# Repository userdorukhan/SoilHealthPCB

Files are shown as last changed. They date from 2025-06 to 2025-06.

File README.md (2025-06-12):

# 🌱 SoilHealth – Smart Agriculture PCB Project

**SoilHealth** is a smart environmental monitoring system designed as part of the Hope DeCal at UC Berkeley. This project aims to measure key soil and atmospheric parameters to support precision agriculture, gardening, and sustainability efforts. The custom-designed PCB integrates multiple sensors, solar-powered charging, and wireless data transmission via an ESP32 microcontroller.

---

## 🔧 Features

* **Custom PCB Design** for low-power, compact, and modular sensor integration
* **Solar-Powered System** with a Li-ion battery and charging circuit
* **ESP32 Microcontroller** for sensor interfacing and Wi-Fi communication
* **U.FL Antenna Connector** for extended wireless range
* **Data Logging** to Firebase for real-time remote monitoring

---

## 🌡️ Sensors Used

| Sensor  | Measurement | Notes |
| --- | --- | --- |
| SEN0193 | Soil Moisture | Capacitive, analog output |
| DS18B20 | Soil Temperature | Waterproof, 1-Wire protocol |
| BH1750  | Light Intensity | Digital I2C sensor |
| BME280  | Temperature, Humidity, Pressure | I2C protocol |

---

## ⚡ Power Management

* **Solar Panel Input**
* **Lithium-Ion Battery** charging via onboard circuit
* **Voltage Regulator** to ensure stable 3.3V supply to ESP32 and sensors

---

## 📡 Connectivity

* **Wi-Fi Transmission** via ESP32
* **Firebase Integration** for remote data storage and visualization

---

## 📐 PCB Highlights

* Designed using KiCad
* Double-layer board optimized for low noise and compact routing
* Separate power domain for analog sensors to reduce interference
* Test points for debugging and voltage verification

---

## 🛠️ Future Improvements

* Add onboard SD card logging for offline operation
* Improve power optimization via deep sleep modes
* Add additional sensors (e.g., CO₂, VOC) for advanced monitoring

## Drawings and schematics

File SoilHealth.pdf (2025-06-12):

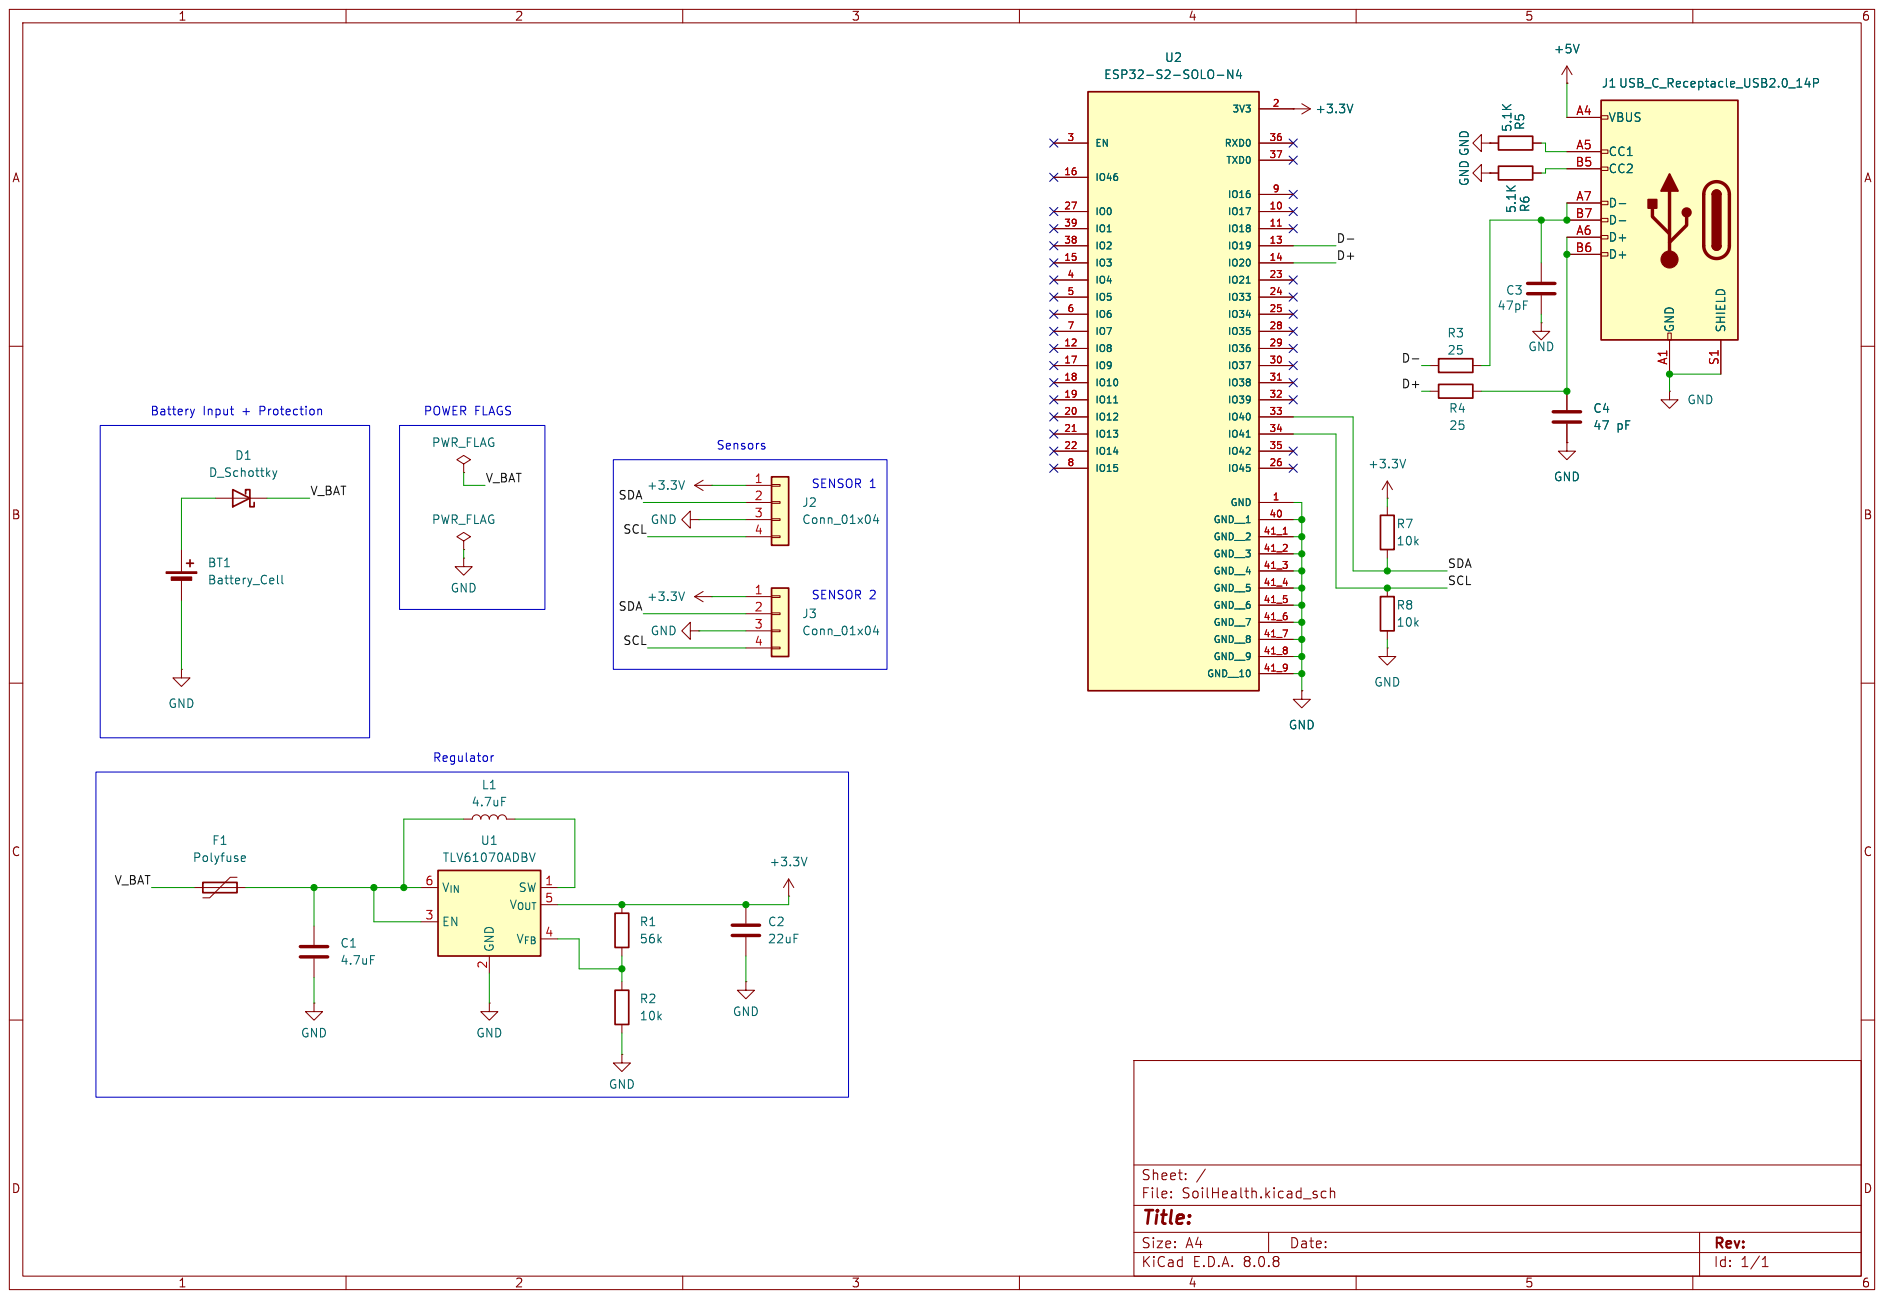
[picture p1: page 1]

Id: 1/1 Title: File: SoilHealth.kicad_sch Sheet: / GND

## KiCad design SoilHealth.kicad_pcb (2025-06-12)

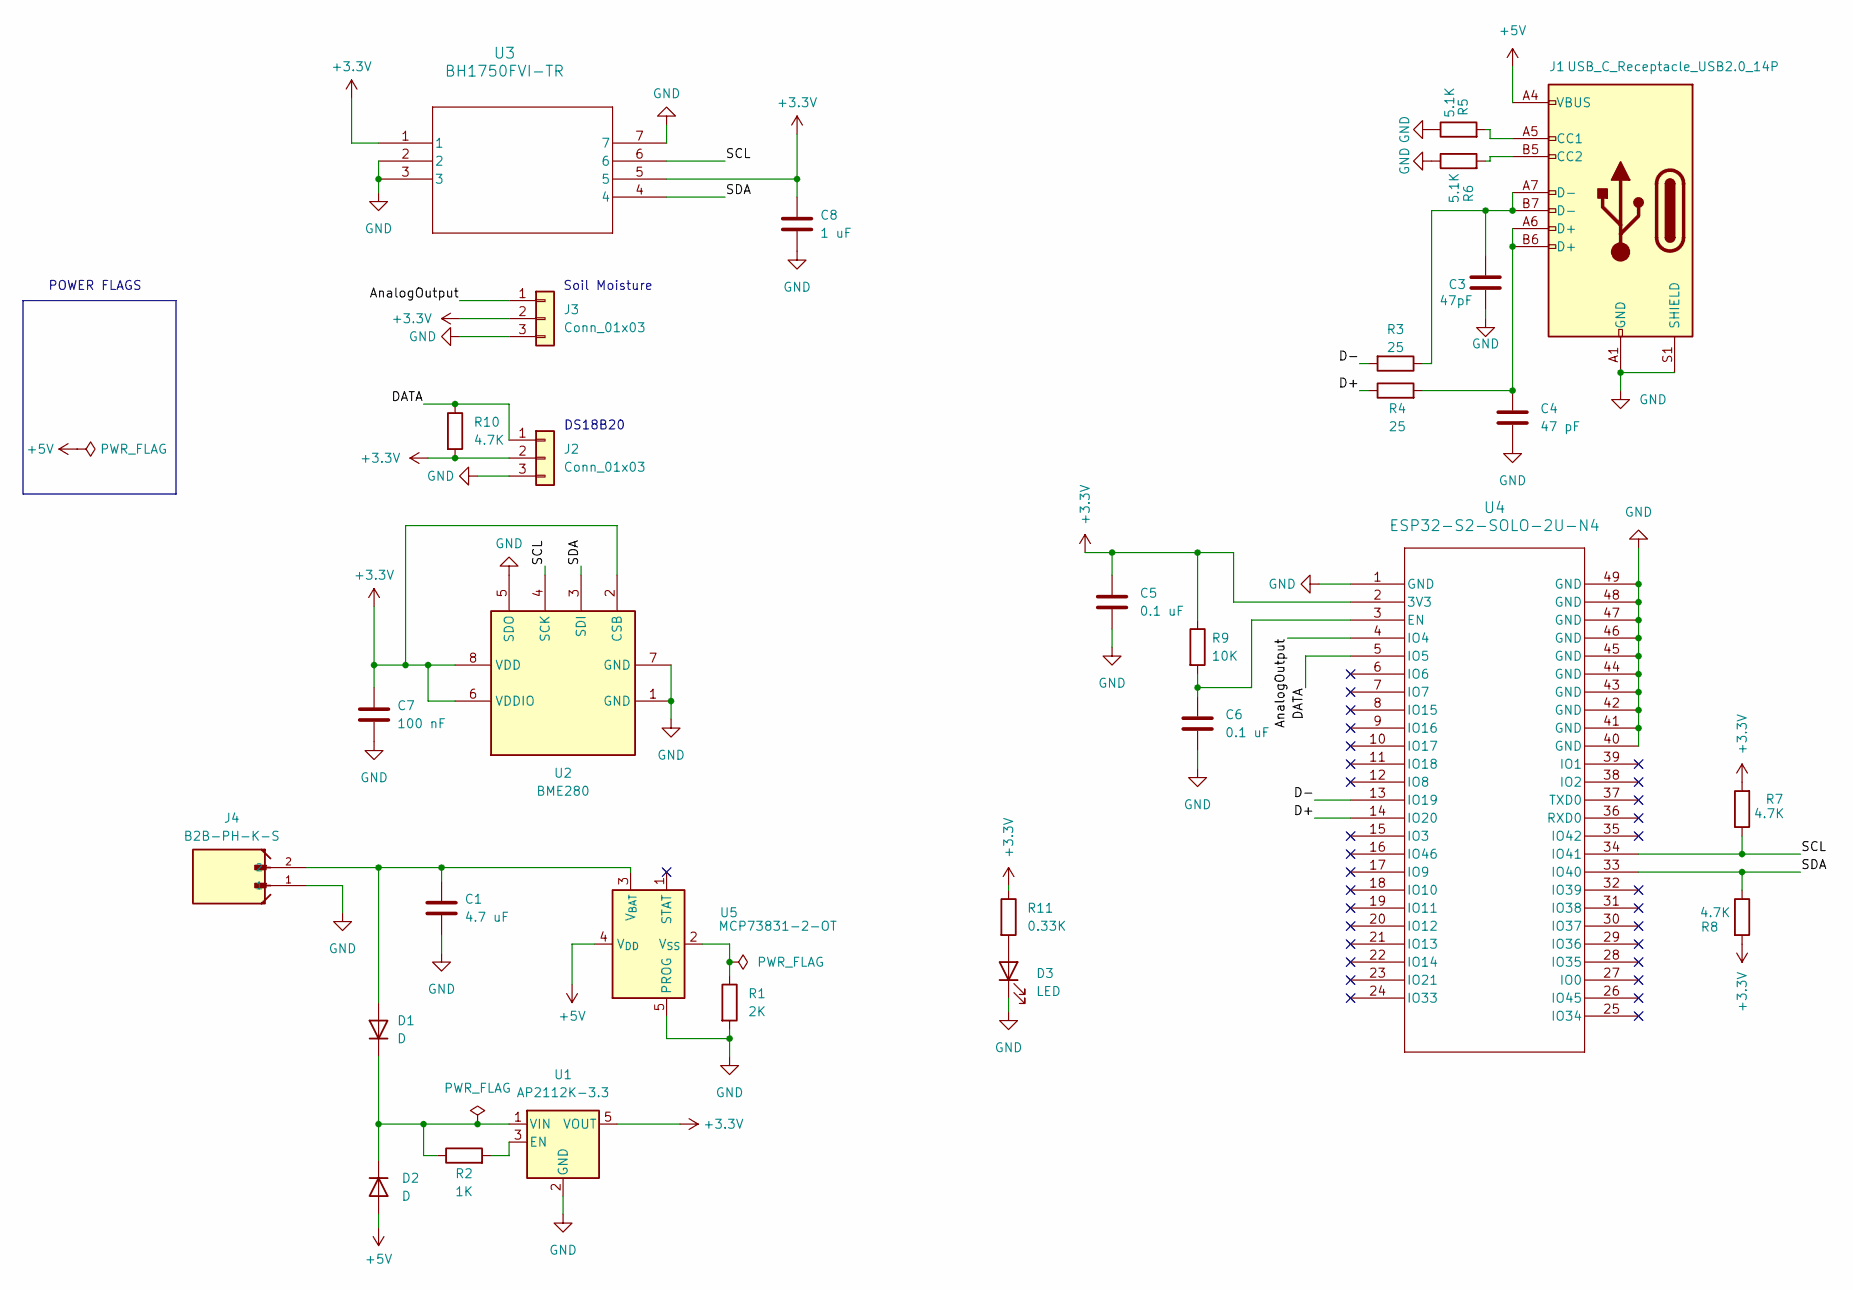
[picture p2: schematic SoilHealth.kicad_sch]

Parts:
C1: 4.7 uF; C_0603_1608Metric_Pad1.08x0.95mm_HandSolder
C3: 47pF; C_0603_1608Metric_Pad1.08x0.95mm_HandSolder
C4: 47 pF; C_0603_1608Metric_Pad1.08x0.95mm_HandSolder
C5, C6: 0.1 uF; C_0603_1608Metric_Pad1.08x0.95mm_HandSolder
C7: 100 nF; C_0603_1608Metric_Pad1.08x0.95mm_HandSolder
C8: 1 uF; C_0603_1608Metric_Pad1.08x0.95mm_HandSolder
D1, D2: D; D_SMA
D3: LED; D_0603_1608Metric_Pad1.05x0.95mm_HandSolder
J1: USB_C_Receptacle_USB2.0_14P; USB_C_Receptacle_GCT_USB4105-xx-A_16P_TopMnt_Horizontal
J2: Conn_01x03; PinSocket_1x03_P2.54mm_Vertical
J3: Conn_01x03; PinHeader_1x03_P2.54mm_Vertical
J4: B2B-PH-K-S; BatteryHead
R1: 2K; R_0603_1608Metric_Pad0.98x0.95mm_HandSolder
R2: 1K; R_0603_1608Metric_Pad0.98x0.95mm_HandSolder
R3, R4: 25; R_0603_1608Metric_Pad0.98x0.95mm_HandSolder
R5, R6: 5.1K; R_0603_1608Metric_Pad0.98x0.95mm_HandSolder
R7, R8, R10: 4.7K; R_0603_1608Metric_Pad0.98x0.95mm_HandSolder
R9: 10K; R_0603_1608Metric_Pad0.98x0.95mm_HandSolder
R11: 0.33K; R_0603_1608Metric_Pad0.98x0.95mm_HandSolder
U1: AP2112K-3.3; SOT-23-5
U2: BME280; Bosch_LGA-8_2.5x2.5mm_P0.65mm_ClockwisePinNumbering
U3: BH1750FVI-TR; LightEmmity
U4: ESP32-S2-SOLO-2U-N4; ESP32-S2-SOLO-2U_EXP
U5: MCP73831-2-OT; SOT-23-5

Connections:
+3.3V: C5.1, C7.1, C8.1, J2.2, J3.2, R7.2, R8.2, R9.1, R10.2, R11.1, U1.5 (VOUT), U2.2 (CSB), U2.6 (VDDIO), U2.8 (VDD), U3.1, U3.5, U4.2 (3V3)
+5V: D2.2 (A), J1.A4 (VBUS), J1.A9 (VBUS), J1.B4 (VBUS), J1.B9 (VBUS), U5.4 (V_{DD})
/AnalogOutput: J3.1, U4.4 (IO4)
/D+: R4.1, U4.14 (IO20)
/D-: R3.2, U4.13 (IO19)
/DATA: J2.1, R10.1, U4.5 (IO5)
/SCL: R7.1, U2.4 (SCK), U3.6, U4.34 (IO41)
/SDA: R8.1, U2.3 (SDI), U3.4, U4.33 (IO40)
GND: C1.2, C3.2, C4.2, C5.2, C6.2, C7.2, C8.2, D3.1 (K), J1.A1 (GND), J1.A12 (GND), J1.B1 (GND), J1.B12 (GND), J1.S1 (SHIELD), J2.3, J3.3, J4.1, R1.2, R5.1, R6.1, U1.2 (GND), U2.1 (GND), U2.5 (SDO), U2.7 (GND), U3.2, U3.3, U3.7, U4.1 (GND), U4.40 (GND), U4.41 (GND), U4.42 (GND), U4.43 (GND), U4.44 (GND), U4.45 (GND), U4.46 (GND), U4.47 (GND), U4.48 (GND), U4.49 (GND), U5.5 (PROG)
unnamed: C3.1, J1.A7 (D-), J1.B7 (D-), R3.1
unnamed: C4.1, J1.A6 (D+), J1.B6 (D+), R4.2
unnamed: C1.1, D1.2 (A), J4.2, U5.3 (V_{BAT})
unnamed: D1.1 (K), D2.1 (K), R2.1, U1.1 (VIN)
unnamed: D3.2 (A), R11.2
unnamed: J1.A5 (CC1), R5.2
unnamed: J1.B5 (CC2), R6.2
unnamed: R2.2, U1.3 (EN)
unnamed: C6.1, R9.2, U4.3 (EN)
unnamed: R1.1, U5.2 (V_{SS})

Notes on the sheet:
POWER FLAGS
Soil Moisture
DS18B20

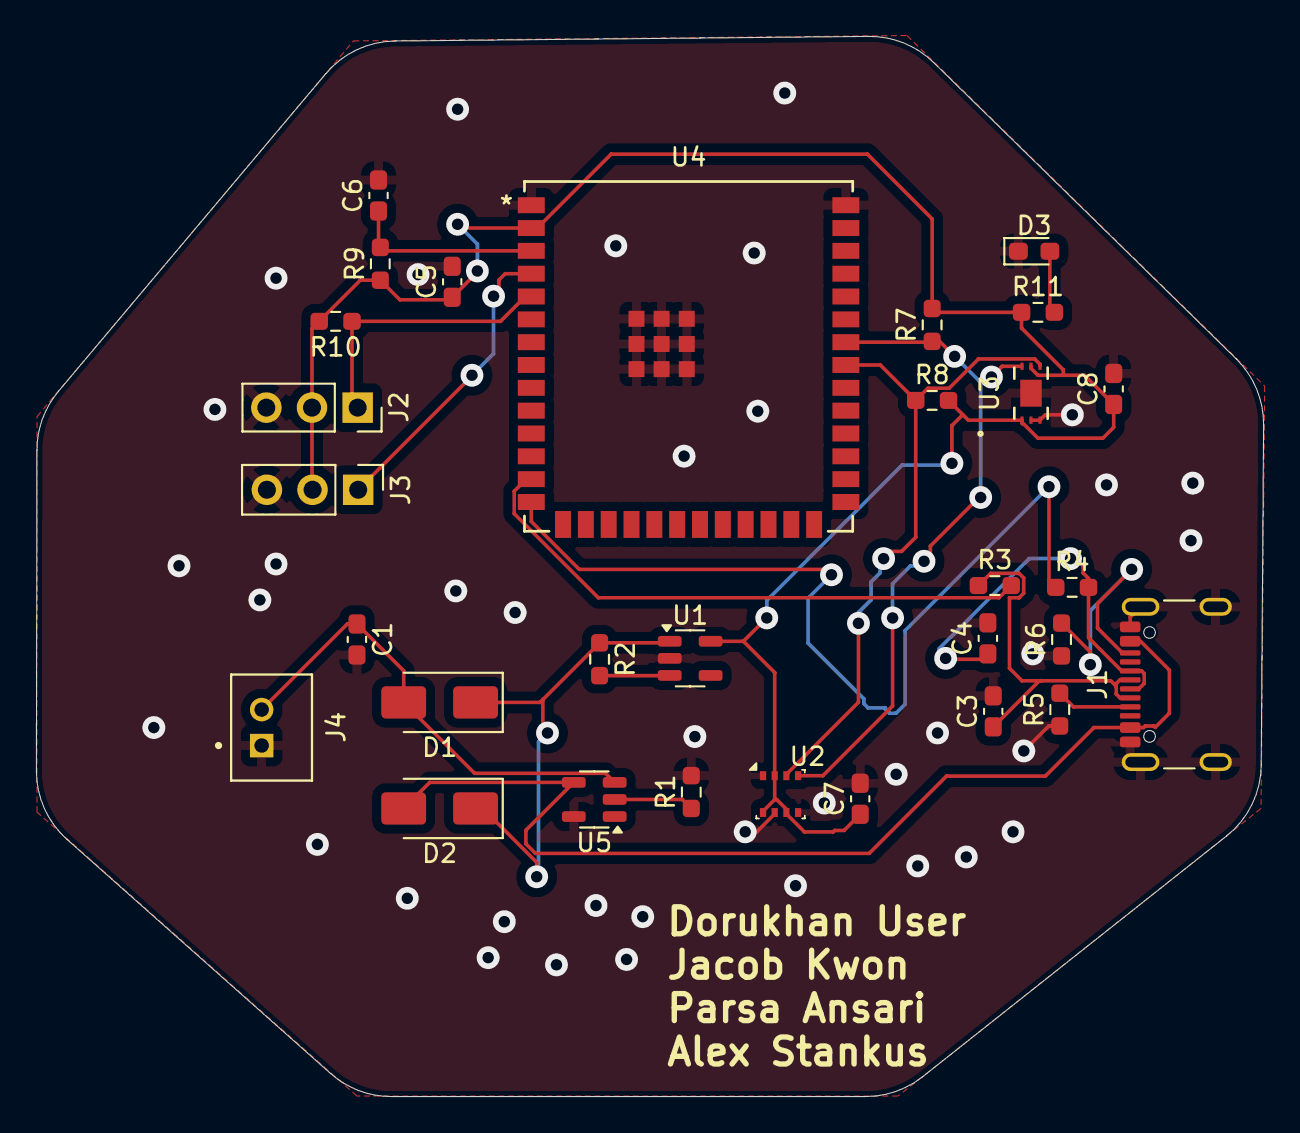
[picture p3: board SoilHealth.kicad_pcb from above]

Board: 2 copper layers, 68.3 x 59.0 mm, 30 parts (0 on the bottom side), 19 nets.
